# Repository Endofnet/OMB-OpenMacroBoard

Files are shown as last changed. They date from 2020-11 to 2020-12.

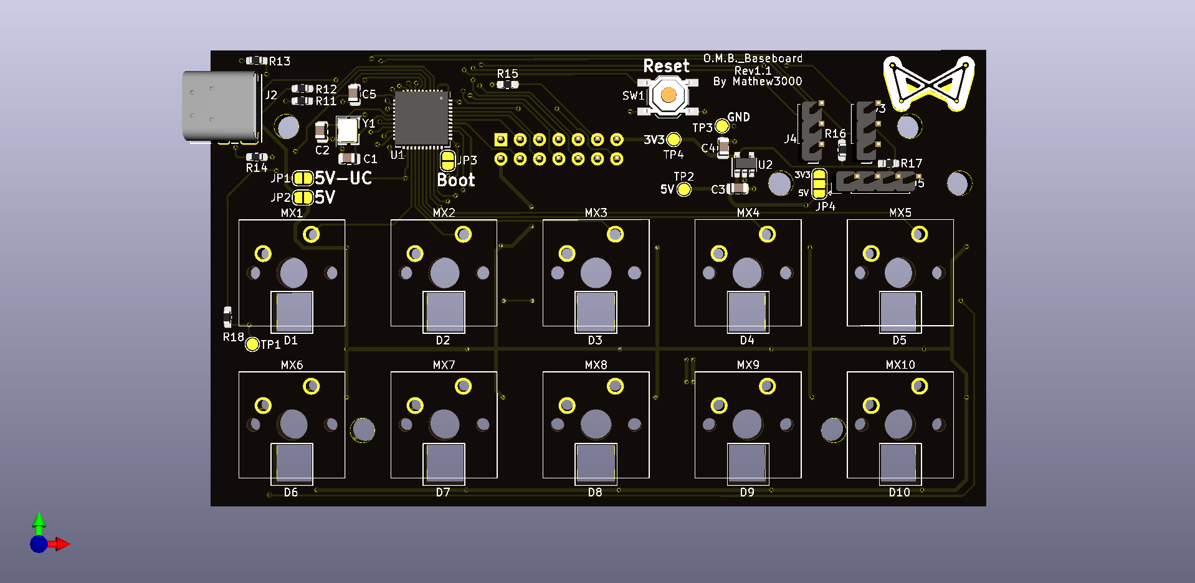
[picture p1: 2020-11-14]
MacroBoard_Preview.png

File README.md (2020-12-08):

# OMB-OpenMacroBoard

These are the PCB-Files for the OpenMacroBoard (O.M.B.) the O.M.B. is a 10-key, programmable keyboard.
It is meant to be used with the [OMB-OpenMacroBoardFirmware](https://github.com/Endofnet/OMB-OpenMacroBoard-Firmware "OMB-Firmware on GitHub").<br/>
As the board uses an Atmega32u4 it should be possible to use it with QMK if ported, but that is currently not implemented.
The first released version of the O.M.B. is version 1.1.

## Features

* 10 mechanical keys
* individual rgb lighting per key
* upcomming support for mini OLED-screens
* USB Type-C connector!
* custom expandable with breakout header

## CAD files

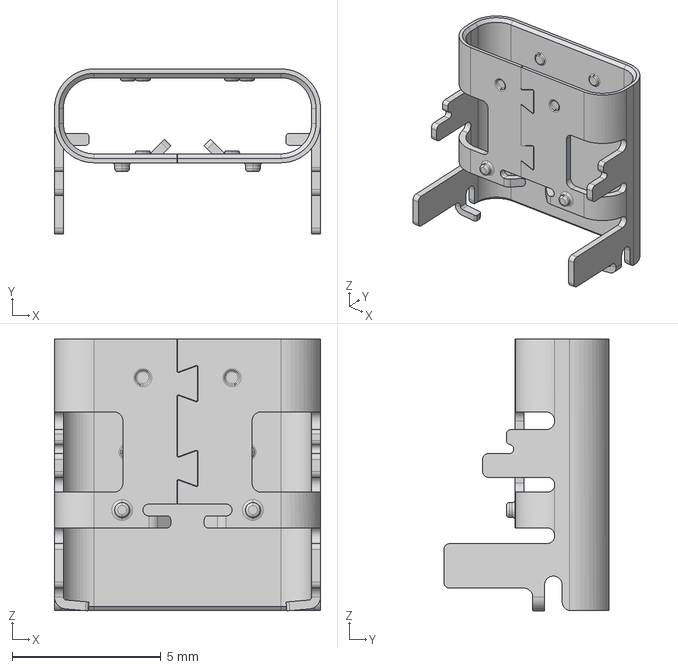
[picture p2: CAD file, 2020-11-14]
USB4085-GF-A_2.step
8.95 x 5.56 x 9.15 mm

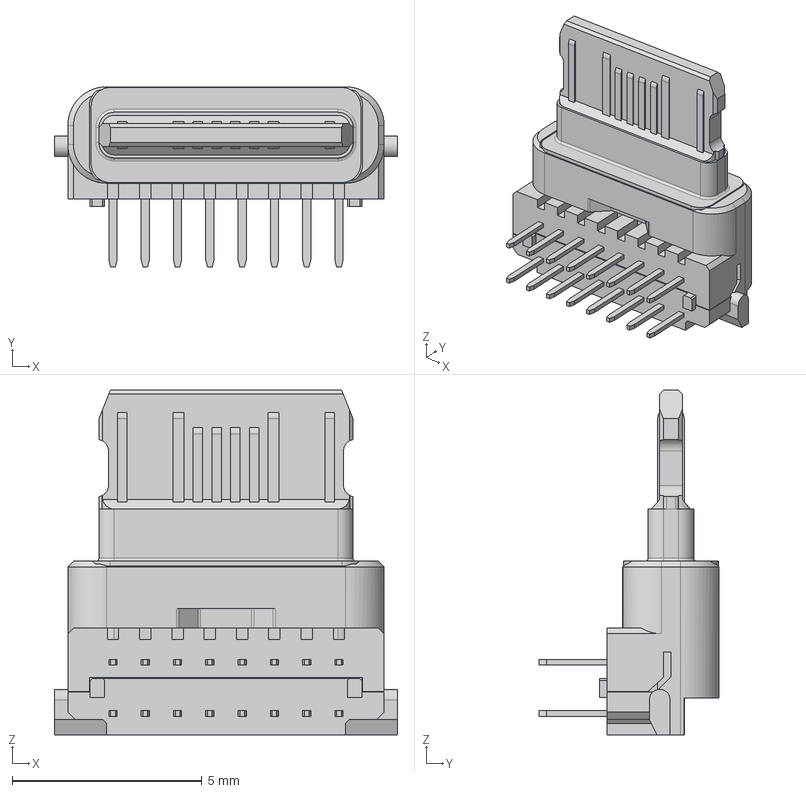
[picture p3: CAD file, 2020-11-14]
USB4085-GF-A_1.step
9.03 x 4.75 x 9.07 mm

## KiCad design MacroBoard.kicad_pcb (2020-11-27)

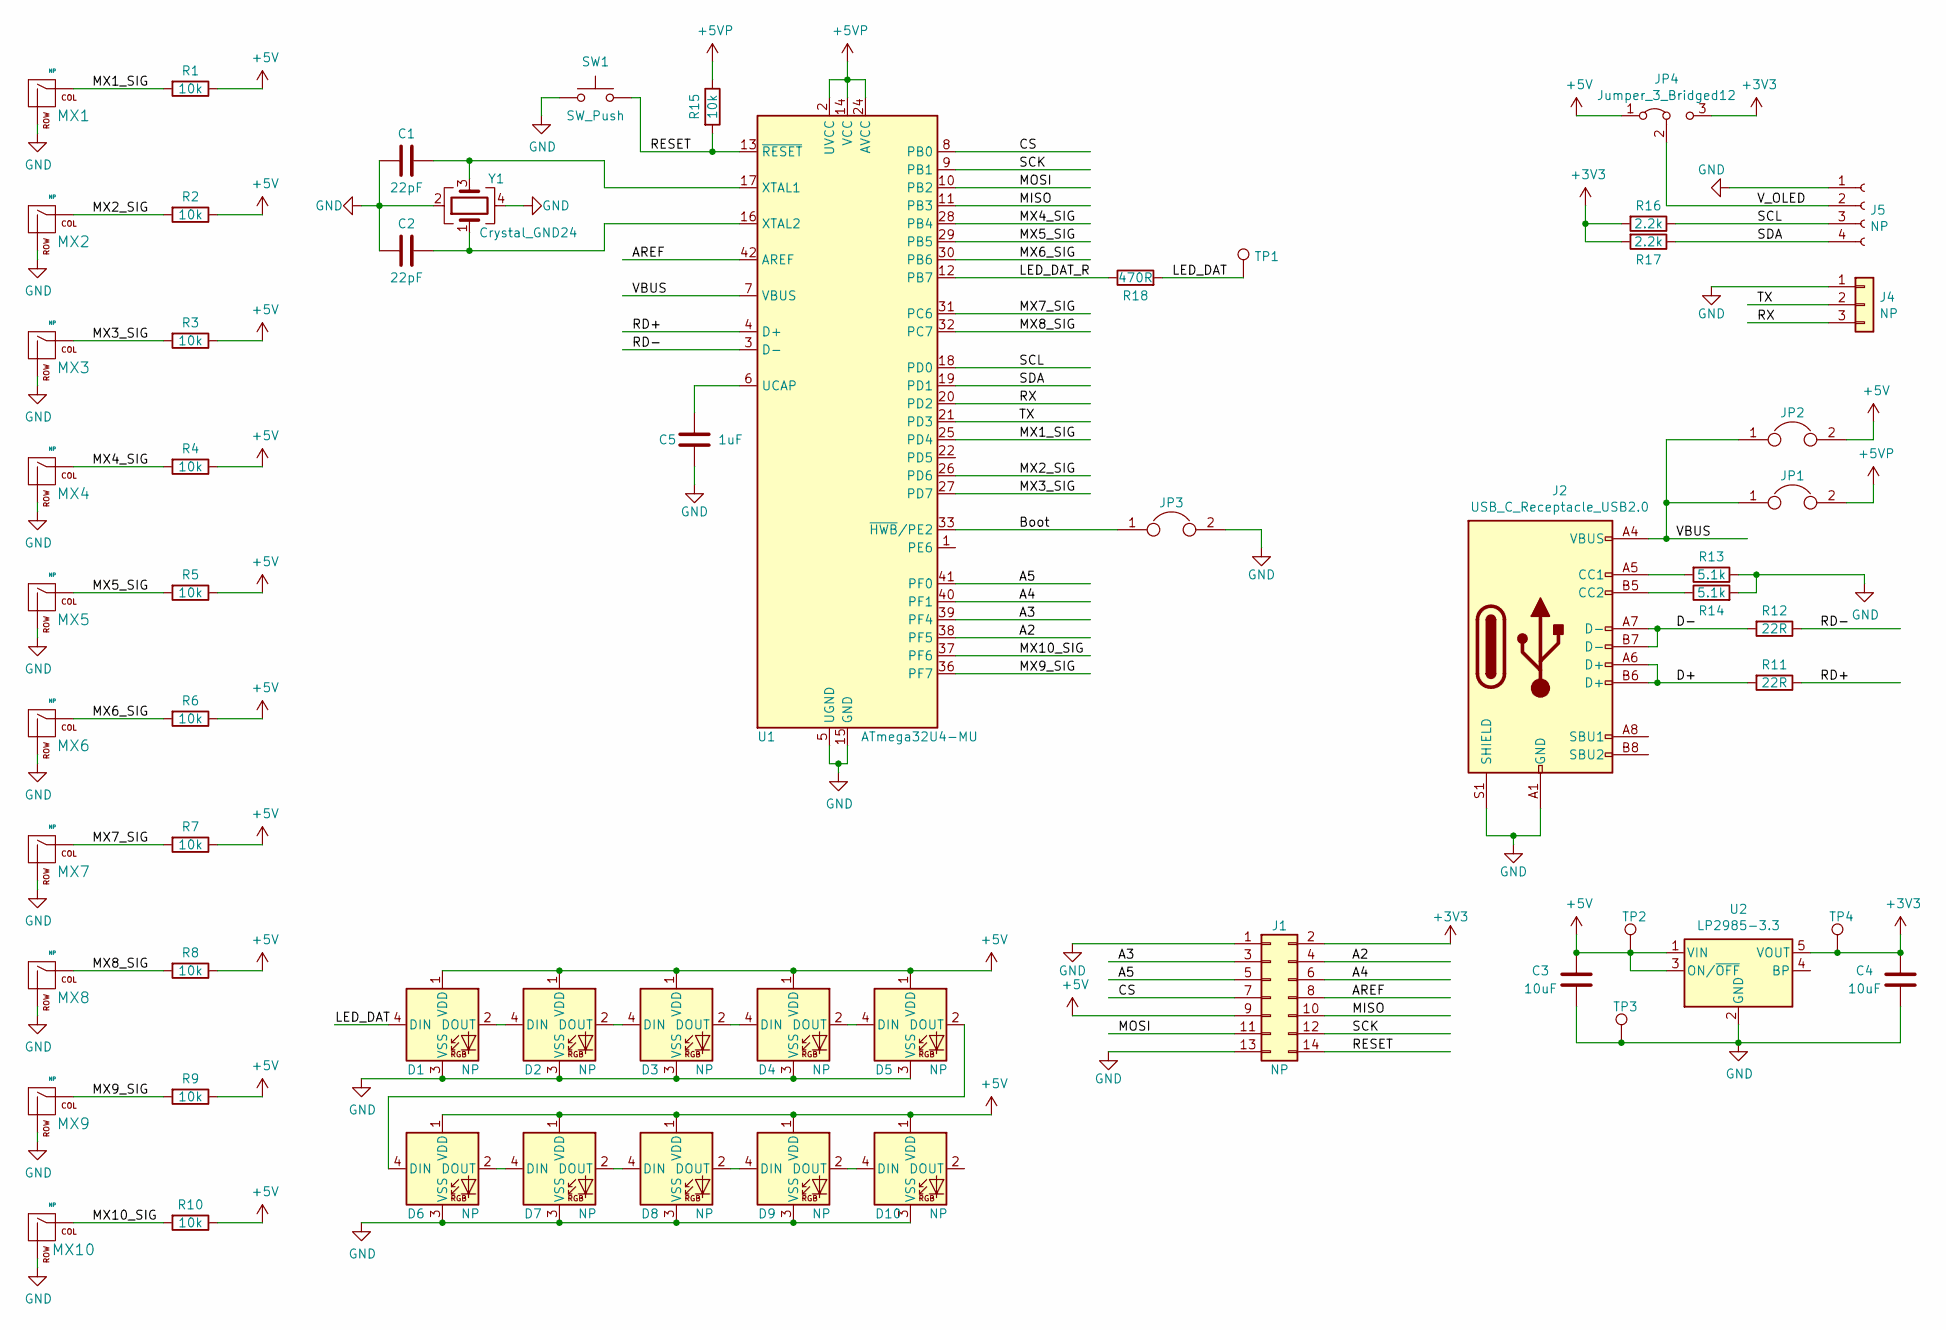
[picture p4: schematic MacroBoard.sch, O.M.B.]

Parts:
C1, C2: 22pF; C_0805_2012Metric; JLCID C15850
C3, C4: 10uF; C_0805_2012Metric; JLCID C15850
C5: 1uF; C_0805_2012Metric; JLCID C15850
D1, D2, D3, D4, D5, D6, D7, D8, D9, D10: NP; WS2812b_ThroughBoard
J1: NP; PinHeader_2x07_P2.54mm_Vertical
J2: USB_C_Receptacle_USB2.0; USB_C_Receptacle_GCT_USB4085
J4: NP; PinHeader_1x03_P2.54mm_Vertical
J5: NP; PinHeader_1x04_P2.54mm_Vertical
JP1, JP2, JP3: Jumper; SolderJumper-2_P1.3mm_Open_RoundedPad1.0x1.5mm
JP4: Jumper_3_Bridged12; SolderJumper-3_P1.3mm_Open_RoundedPad1.0x1.5mm
MX1, MX2, MX3, MX4, MX5, MX6, MX7, MX8, MX9, MX10: NP; SW_Cherry_MX_1.00u_PCB
R1, R2, R3, R4, R5, R6, R7, R8, R9, R10: 10k; R_0805_2012Metric_Pad1.15x1.40mm_HandSolder
R11, R12: 22R; R_0603_1608Metric_Pad1.05x0.95mm_HandSolder; JLCID C27834
R13, R14: 5.1k; R_0603_1608Metric_Pad1.05x0.95mm_HandSolder; JLCID C27834
R15: 10k; R_0603_1608Metric_Pad1.05x0.95mm_HandSolder; JLCID C17414
R16, R17: 2.2k; R_0603_1608Metric_Pad1.05x0.95mm_HandSolder; JLCID C17520
R18: 470R; R_0603_1608Metric_Pad1.05x0.95mm_HandSolder; JLCID C17710
SW1: SW_Push; SW_SPST_TL3342; JLCID C318884
TP1, TP2, TP3, TP4: TestPoint; TestPoint_Pad_D1.5mm
U1: ATmega32U4-MU; QFN-44-1EP_7x7mm_P0.5mm_EP5.2x5.2mm; JLCID C45874
U2: LP2985-3.3; SOT-23-5; JLCID C89826
Y1: Crystal_GND24; Crystal_SMD_3225-4Pin_3.2x2.5mm; JLCID C13738

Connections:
+3V3: C4.1, J1.2, JP4.3 (B), R16.2, R17.2, TP4.1, U2.5 (VOUT)
+5V: C3.1, D1.1 (VDD), D2.1 (VDD), D3.1 (VDD), D4.1 (VDD), D5.1 (VDD), D6.1 (VDD), D7.1 (VDD), D8.1 (VDD), D9.1 (VDD), D10.1 (VDD), J1.9, JP2.2, JP4.1 (A), R1.1, R2.1, R3.1, R4.1, R5.1, R6.1, R7.1, R8.1, R9.1, R10.1, TP2.1, U2.1 (VIN), U2.3 (ON/~OFF~)
+5VP: JP1.2, R15.1, U1.2 (UVCC), U1.14 (VCC), U1.24 (AVCC), U1.34 (VCC), U1.44 (AVCC)
/A2: J1.4, U1.38 (PF5)
/A3: J1.3, U1.39 (PF4)
/A4: J1.6, U1.40 (PF1)
/A5: J1.5, U1.41 (PF0)
/AREF: J1.8, U1.42 (AREF)
/Boot: JP3.1, U1.33 (~HWB~/PE2)
/CS: J1.7, U1.8 (PB0)
/D+: J2.A6 (D+), J2.B6 (D+), R11.2
/D-: J2.A7 (D-), J2.B7 (D-), R12.2
/LED_DAT: D1.4 (DIN), R18.2, TP1.1
/LED_DAT_R: R18.1, U1.12 (PB7)
/MISO: J1.10, U1.11 (PB3)
/MOSI: J1.11, U1.10 (PB2)
/MX1_SIG: MX1.1 (COL), R1.2, U1.25 (PD4)
/MX2_SIG: MX2.1 (COL), R2.2, U1.26 (PD6)
/MX3_SIG: MX3.1 (COL), R3.2, U1.27 (PD7)
/MX4_SIG: MX4.1 (COL), R4.2, U1.28 (PB4)
/MX5_SIG: MX5.1 (COL), R5.2, U1.29 (PB5)
/MX6_SIG: MX6.1 (COL), R6.2, U1.30 (PB6)
/MX7_SIG: MX7.1 (COL), R7.2, U1.31 (PC6)
/MX8_SIG: MX8.1 (COL), R8.2, U1.32 (PC7)
/MX9_SIG: MX9.1 (COL), R9.2, U1.36 (PF7)
/MX10_SIG: MX10.1 (COL), R10.2, U1.37 (PF6)
/RD+: R11.1, U1.4 (D+)
/RD-: R12.1, U1.3 (D-)
/RESET: J1.14, R15.2, SW1.2, U1.13 (~RESET)
/RX: J4.3, U1.20 (PD2)
/SCK: J1.12, U1.9 (PB1)
/SCL: J5.3, R16.1, U1.18 (PD0)
/SDA: J5.4, R17.1, U1.19 (PD1)
/TX: J4.2, U1.21 (PD3)
/VBUS: J2.A4 (VBUS), J2.A9 (VBUS), J2.B4 (VBUS), J2.B9 (VBUS), JP1.1, JP2.1, U1.7 (VBUS)
/V_OLED: J5.2, JP4.2 (C)
GND: C1.2, C2.2, C3.2, C4.2, C5.2, D1.3 (VSS), D2.3 (VSS), D3.3 (VSS), D4.3 (VSS), D5.3 (VSS), D6.3 (VSS), D7.3 (VSS), D8.3 (VSS), D9.3 (VSS), D10.3 (VSS), J1.1, J1.13, J2.A1 (GND), J2.A12 (GND), J2.B1 (GND), J2.B12 (GND), J2.S1 (SHIELD), J4.1, J5.1, JP3.2, MX1.2 (ROW), MX2.2 (ROW), MX3.2 (ROW), MX4.2 (ROW), MX5.2 (ROW), MX6.2 (ROW), MX7.2 (ROW), MX8.2 (ROW), MX9.2 (ROW), MX10.2 (ROW), R13.1, R14.2, SW1.1, TP3.1, U1.5 (UGND), U1.15 (GND), U1.23 (GND), U1.35 (GND), U1.43 (GND), U1.45 (GND), U2.2 (GND), Y1.2, Y1.4
unnamed: C1.1, U1.17 (XTAL1), Y1.3
unnamed: C2.1, U1.16 (XTAL2), Y1.1
unnamed: C5.1, U1.6 (UCAP)
unnamed: D1.2 (DOUT), D2.4 (DIN)
unnamed: D2.2 (DOUT), D3.4 (DIN)
unnamed: D3.2 (DOUT), D4.4 (DIN)
unnamed: D4.2 (DOUT), D5.4 (DIN)
unnamed: D5.2 (DOUT), D6.4 (DIN)
unnamed: D6.2 (DOUT), D7.4 (DIN)
unnamed: D7.2 (DOUT), D8.4 (DIN)
unnamed: D8.2 (DOUT), D9.4 (DIN)
unnamed: D9.2 (DOUT), D10.4 (DIN)
unnamed: J2.A5 (CC1), R13.2
unnamed: J2.B5 (CC2), R14.1

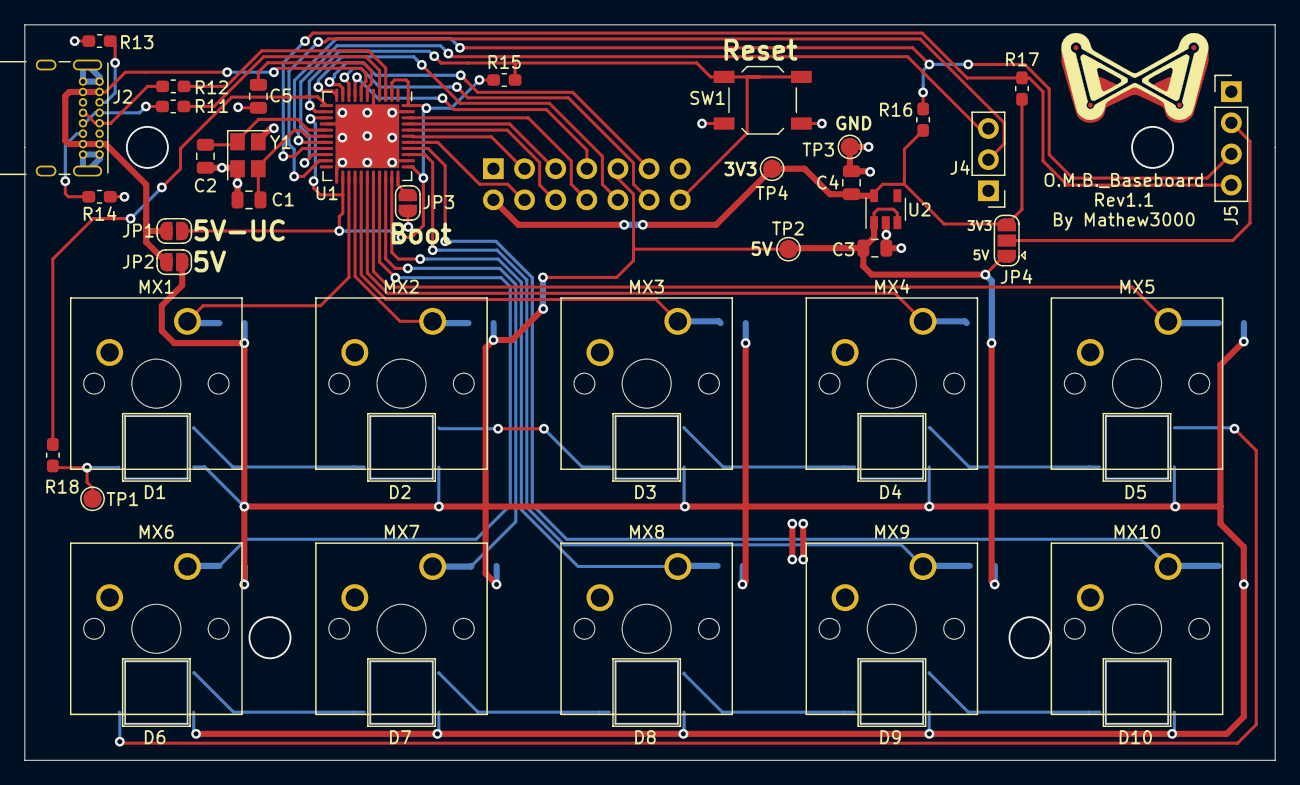
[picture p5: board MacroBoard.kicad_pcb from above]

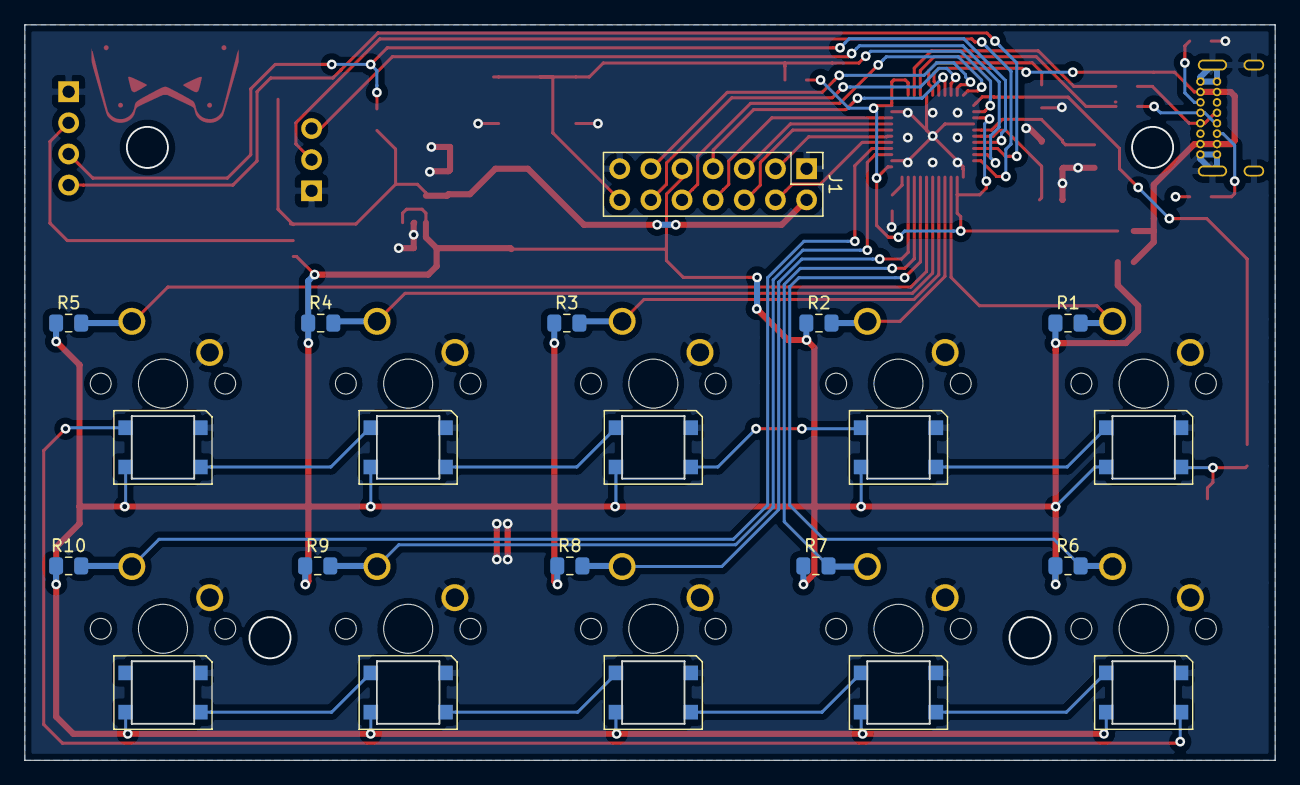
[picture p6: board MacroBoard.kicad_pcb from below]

Board: 2 copper layers, 102.0 x 60.0 mm, 60 parts (11 on the bottom side), 51 nets.

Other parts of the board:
Ref**: Val**; Logo_Color

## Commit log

2020-11-14 Initial Upload of V1.1
    [MacroBoard-B_Cu.gbr, MacroBoard-B_Mask.gbr, MacroBoard-B_Paste.gbr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]
2020-11-14 Added O.M.B. Logo to PCB
    [MacroBoard.kicad_pcb]
2020-11-20 Removed 3 pin i2c connector and replaced it by 4 pin connector for oled attachment
    [MacroBoard.kicad_pcb, MacroBoard.sch]
2020-11-20 Readded Icon
    [MacroBoard.kicad_pcb, MacroBoard.sch]
2020-11-27 Removed output from tracking
    [MacroBoard-B_Cu.gbr, MacroBoard-B_Mask.gbr, MacroBoard-B_Paste.gbr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]
2020-11-27 changed main header pinout to fit standard arduino/avr icsp header
    [MacroBoard.kicad_pcb, MacroBoard.sch]
